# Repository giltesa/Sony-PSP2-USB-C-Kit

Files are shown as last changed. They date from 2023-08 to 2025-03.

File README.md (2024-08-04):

# Sony PSP 2 USB-C Kit

The **Sony PSP 2: USB-C Kit** is a board that allows to replace the original charging connector for a modern and standard **USB-C**.

**If your original connector is too old or damaged** and you need a new one, or **if you would like to charge your Sony PSP with a standard USB-C charger**, like the charger of your phone, laptop, you can with this board.

This board is compatible with these models:

*   Sony PSP 2000
*   Sony PSP 3000

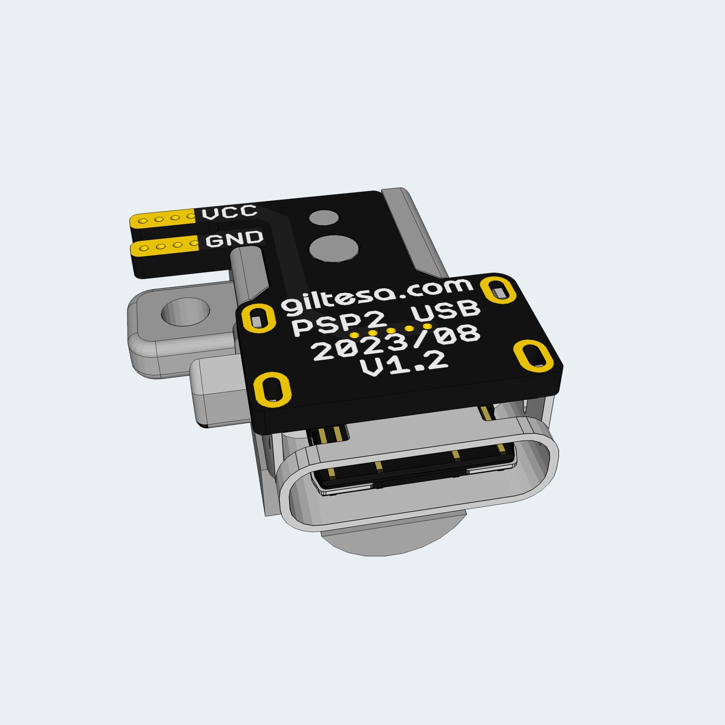
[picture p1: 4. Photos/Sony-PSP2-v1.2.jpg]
Sony-PSP-USB-C


## Would you like it?

https://shop.giltesa.com/product/sony-psp-2000-3000-usb-c-kit/

## More

- [giltesa.com](https://giltesa.com "giltesa.com")
- [twitter.com](https://twitter.com/giltesa "twitter.com")

## License

This project is licensed under a **Creative Commons** license:
**[Attribution-NonCommercial-ShareAlike 4.0 International (CC BY-NC-SA 4.0) ](https://creativecommons.org/licenses/by-nc-sa/4.0/)**

Check the [LICENSE.md](LICENSE.md) for more information.

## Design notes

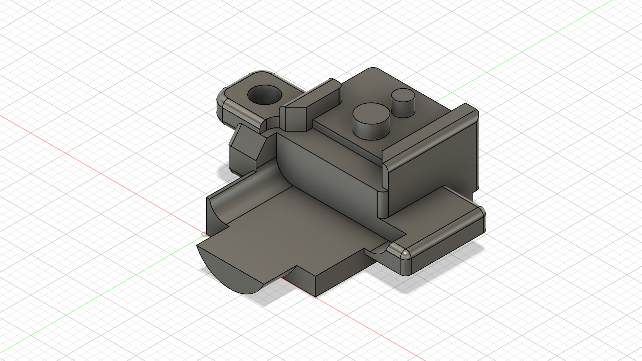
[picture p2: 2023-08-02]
2. Renders, 3D models/Plastic holder/Sony PSP 2000 v5 v14_1.png

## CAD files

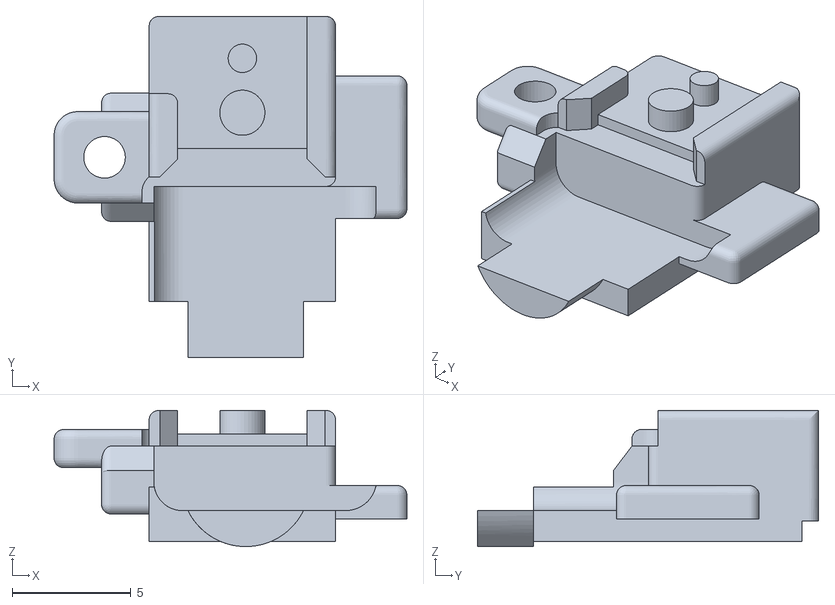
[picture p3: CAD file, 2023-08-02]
2. Renders, 3D models/Plastic holder/Sony PSP 2000 v5 v14.stl
14.9 x 14.3 x 5.73

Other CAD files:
2. Renders, 3D models/Plastic holder/Sony PSP 2000 v5 v14.f3d
2. Renders, 3D models/Sony PSP v1.2.skp

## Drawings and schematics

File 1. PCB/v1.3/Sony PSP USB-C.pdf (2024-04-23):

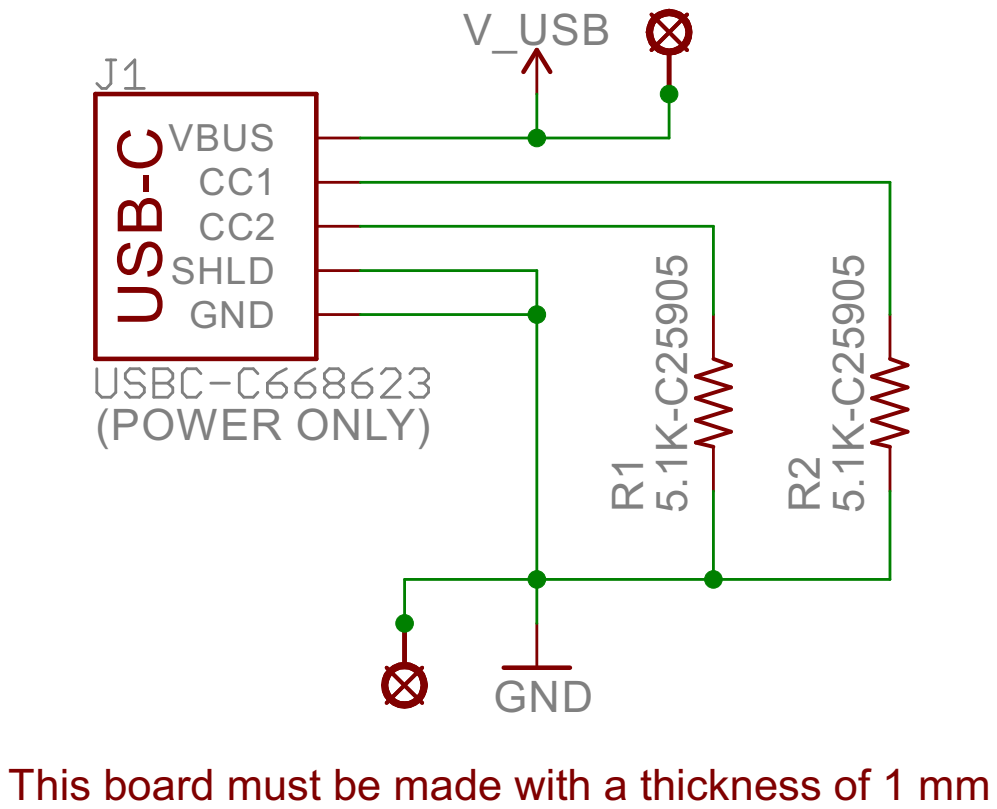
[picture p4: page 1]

This board must be made with a thickness of 1 mm

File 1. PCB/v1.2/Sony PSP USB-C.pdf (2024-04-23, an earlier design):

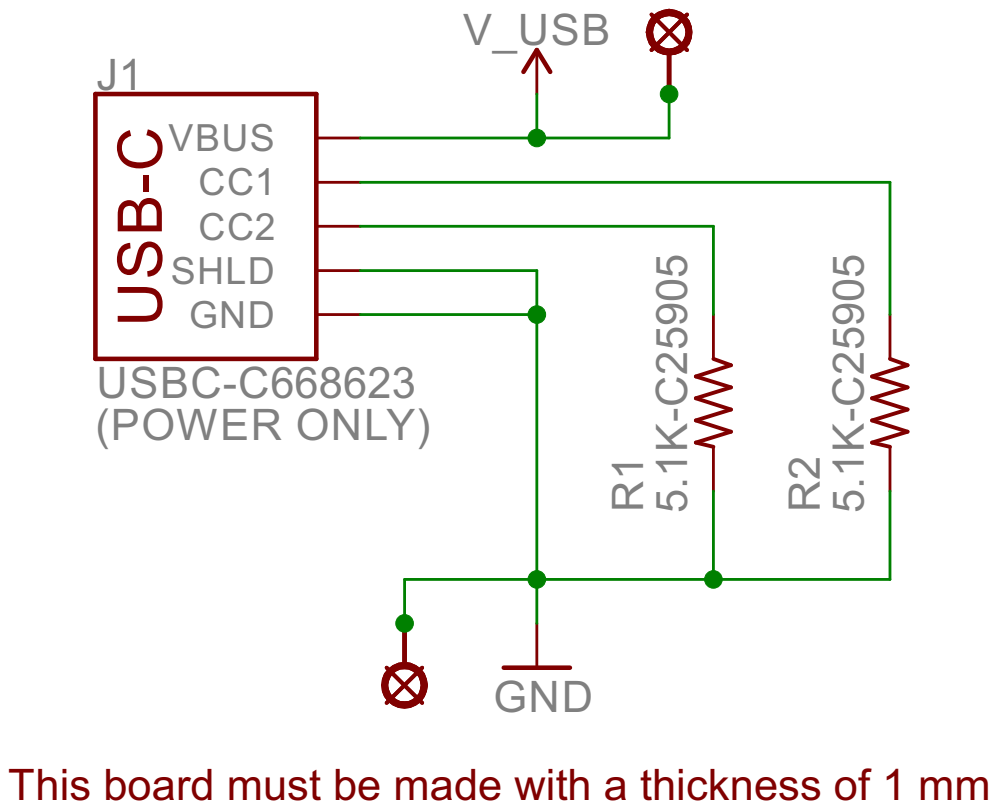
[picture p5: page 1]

This board must be made with a thickness of 1 mm

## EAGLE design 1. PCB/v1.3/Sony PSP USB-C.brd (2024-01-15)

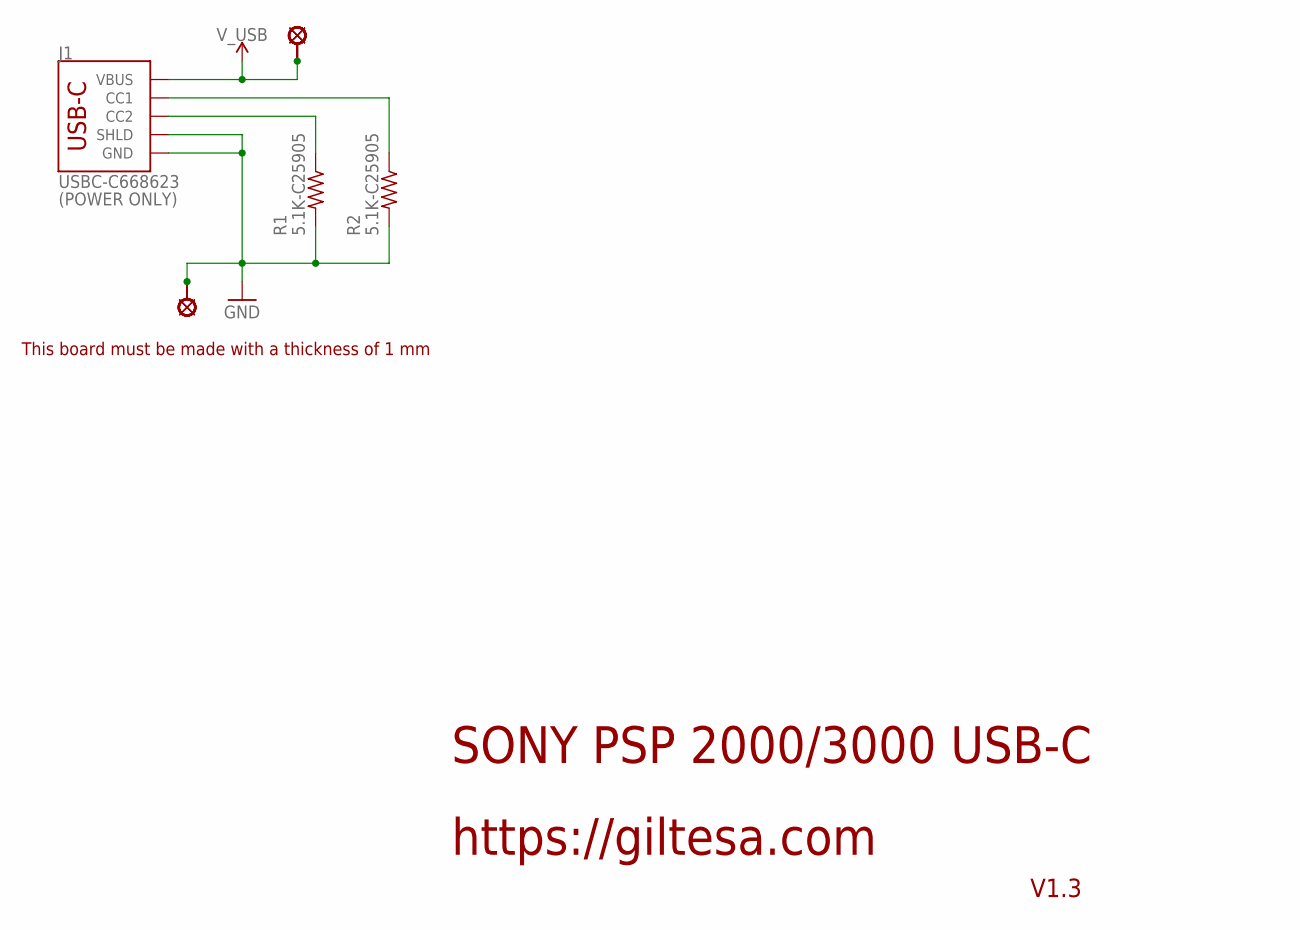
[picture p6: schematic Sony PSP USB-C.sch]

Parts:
J1: USBC-C668623; USB-C_6P
R1, R2: 5.1K-C25905; R0402
U$1, U$2, U$3, U$4: SOLDER_PAD_N3DS; N3DS_TPAD

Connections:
GND: J1.A12-GND (GND), J1.B12-GND (GND), J1.SHLD1 (SHLD), J1.SHLD2 (SHLD), J1.SHLD3 (SHLD), J1.SHLD4 (SHLD), R1.2, R2.2, U$1.1, U$4.1
unnamed: J1.B5 (CC2), R1.1
unnamed: J1.A5 (CC1), R2.1
V_USB: J1.A9-VBUS (VBUS), J1.B9-VBUS (VBUS), U$2.1, U$3.1

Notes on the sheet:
SONY PSP 2000/3000 USB-C
https://giltesa.com
V1.3
This board must be made with a thickness of 1 mm
(POWER ONLY)

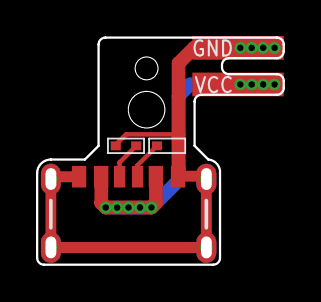
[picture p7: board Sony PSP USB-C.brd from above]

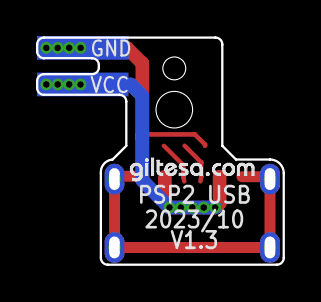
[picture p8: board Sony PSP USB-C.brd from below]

Board: 2 copper layers, 13.7 x 12.6 mm, 8 parts (3 on the bottom side), 4 nets.

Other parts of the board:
U$11: GILTESA.COM_MASK_7MM

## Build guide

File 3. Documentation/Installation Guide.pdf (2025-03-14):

# USB-C KIT For

# Sony PSP 2000 Sony PSP 3000

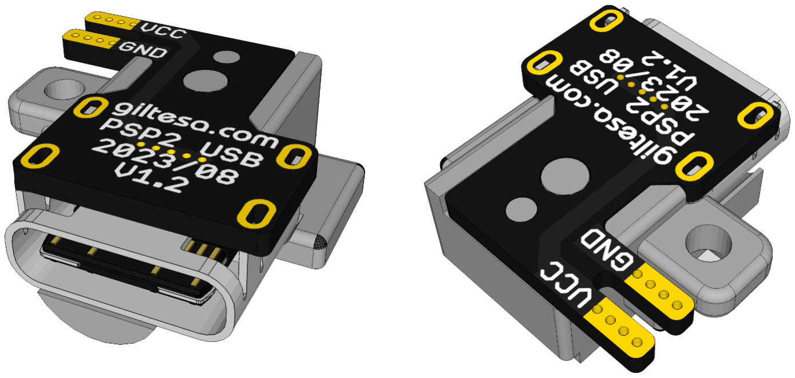
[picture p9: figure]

### PRODUCT

HTTPS://SHOP.GILTESA.COM/PRODUCT/SONY-PSP-2000-3000-USB-C-KIT

# PLEASE READ THROUGH THESE INSTRUCTIONS

ENTIRELY BEFORE ATTEMPTING TO INSTALL.

# WARNING: IF YOU ARE NOT COMFORTABLE WITH SOLDERING, OR PERFORMING ANY STEP IN THIS

GUIDE, DO NOT PERFORM THE INSTALL YOURSELF.

# FIND SOMEONE WHO IS COMFORTABLE TO DO IT FOR

YOU.

INDEX

# Description

The Sony PSP: USB-C Kit is a board that allows to replace the original charging connector for a modern and standard USB-C.

If your original connector is too old or damaged and you need a new one, or if you would like to charge your Sony PSP with a standard USB-C charger, like the charger of your phone, laptop, you can with this kit.

This board is compatible with these two models:

- Sony PSP 2000
- Sony PSP 3000

# FEATURES

- Plastic holder made by resin 3D printer.
- Charging your Sony PSP with:
- USB power banks
- USB-A chargers
- USB-C chargers
- USB-C PD chargers (normal speed, not fast)
- USB-A to USB-C cables
- USB-C to USB-C cables

# INCLUDED

- 1 board.
- 1 plastic part to holder the USB board (random color: Grey/Black)
- 2 Heat shrink tube.

# Recommended / REQUIRED (NOT INCLUDED)

- The power cable from the original connector.
- Phillips screwdriver
- Soldering iron
- Tin
- Cutting plier
- Cutter
- Tweezers
- Instant glue (Loctite, Super Glue)

# Board details

This tiny board has 2 pads in about 2cm²
surface, which means it requires good soldering skills. The following explains what each pad is for.
Version 1.2 and earlier: | Version 1.3 and onwards:

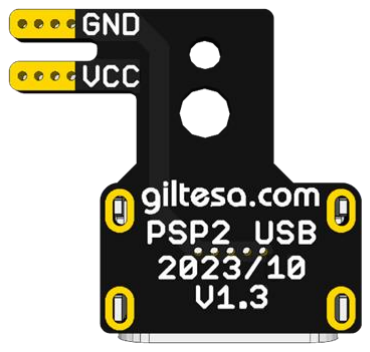
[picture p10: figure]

The pads are inverted, as we noticed that this prevents the cables from twisting during installation.

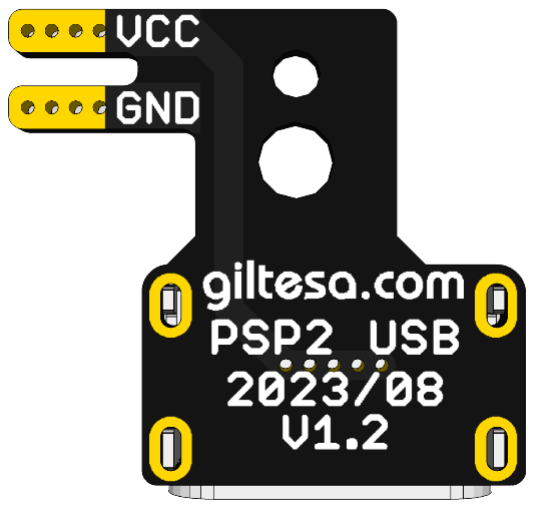
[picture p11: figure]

The pads are:

1. VCC: | The 5V line from the USB-C.
2. GND: | The ground pad.

# Test the board!

Before starting the installation, you should test the board. If it doesn’t work contact me for a replacement (https://shop.giltesa.com/refund-policy/) (all boards are fully tested, but they may damage during the shipping, we try to package them as better as possible), if it works, go ahead with the installation.

Connect the power from your USB charger to the USB-C connector on the board. Then, with a multimeter in voltage measurement mode, check for a 5V reading. If that's the case, continue with the installation.

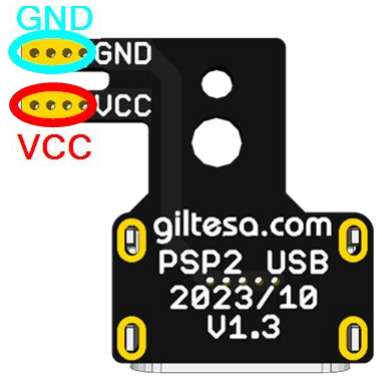
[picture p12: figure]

# INSTALLATION STEPS

## Pre installation Steps

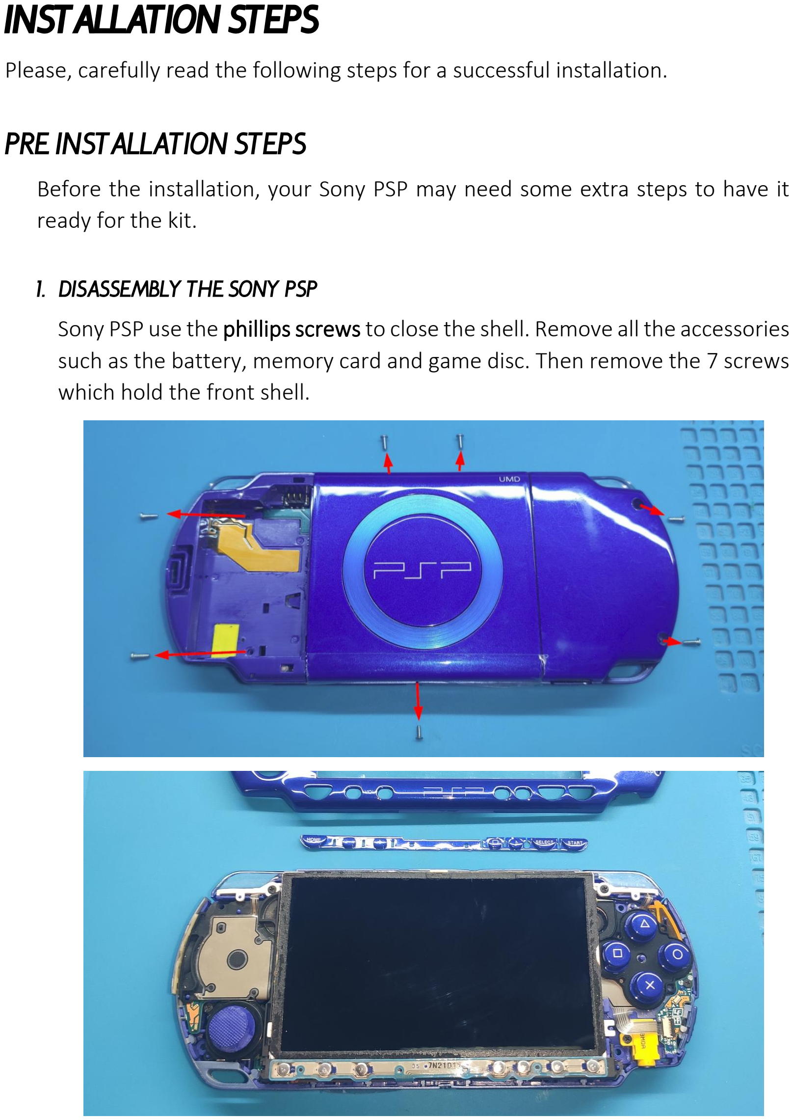
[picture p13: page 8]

Please, carefully read the following steps for a successful installation.

Before the installation, your Sony PSP may need some extra steps to have it ready for the kit.

1. Disassembly the Sony PSP

Sony PSP use the phillips screwsto close the shell. Remove all the accessories such as the battery, memory card and game disc. Then remove the 7 screws which hold the front shell.

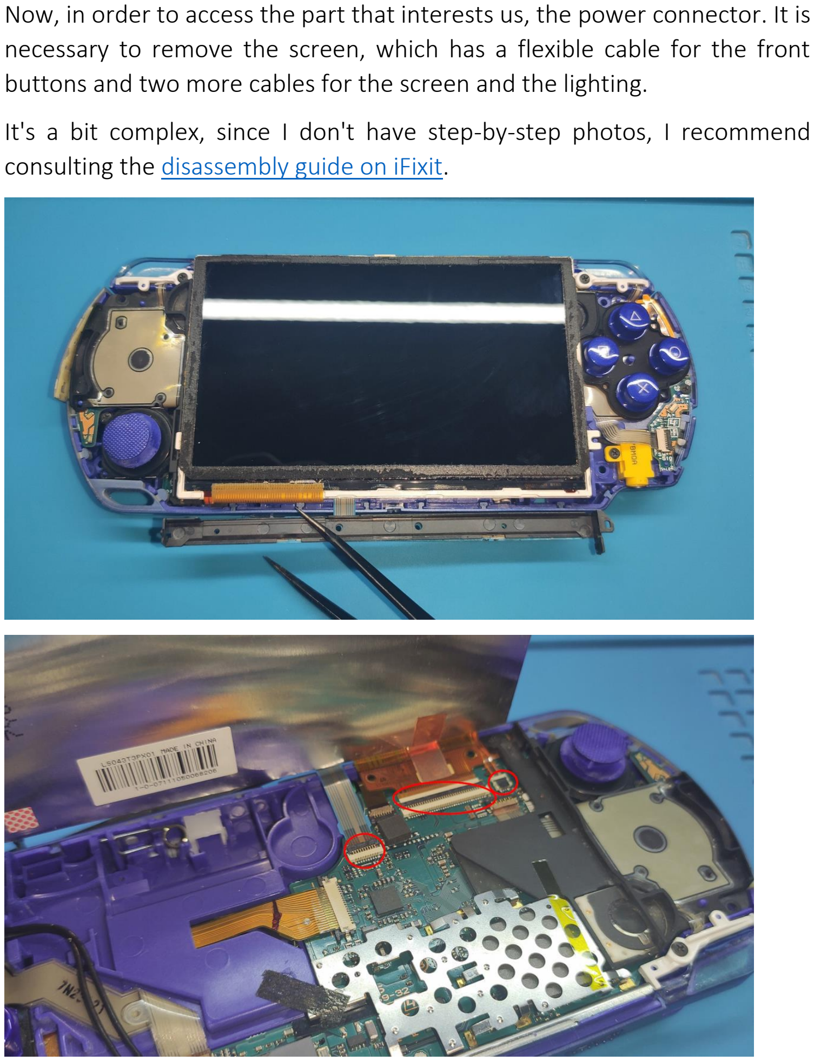
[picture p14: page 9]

Now, in order to access the part that interests us, the power connector. It is necessary to remove the screen, which has a flexible cable for the front buttons and two more cables for the screen and the lighting.

It's a bit complex, since I don't have step-by-step photos, I recommend consulting the disassembly guide on iFixit. (https://www.ifixit.com/Guide/PSP+2000+Logic+Board+Replacement/1272)

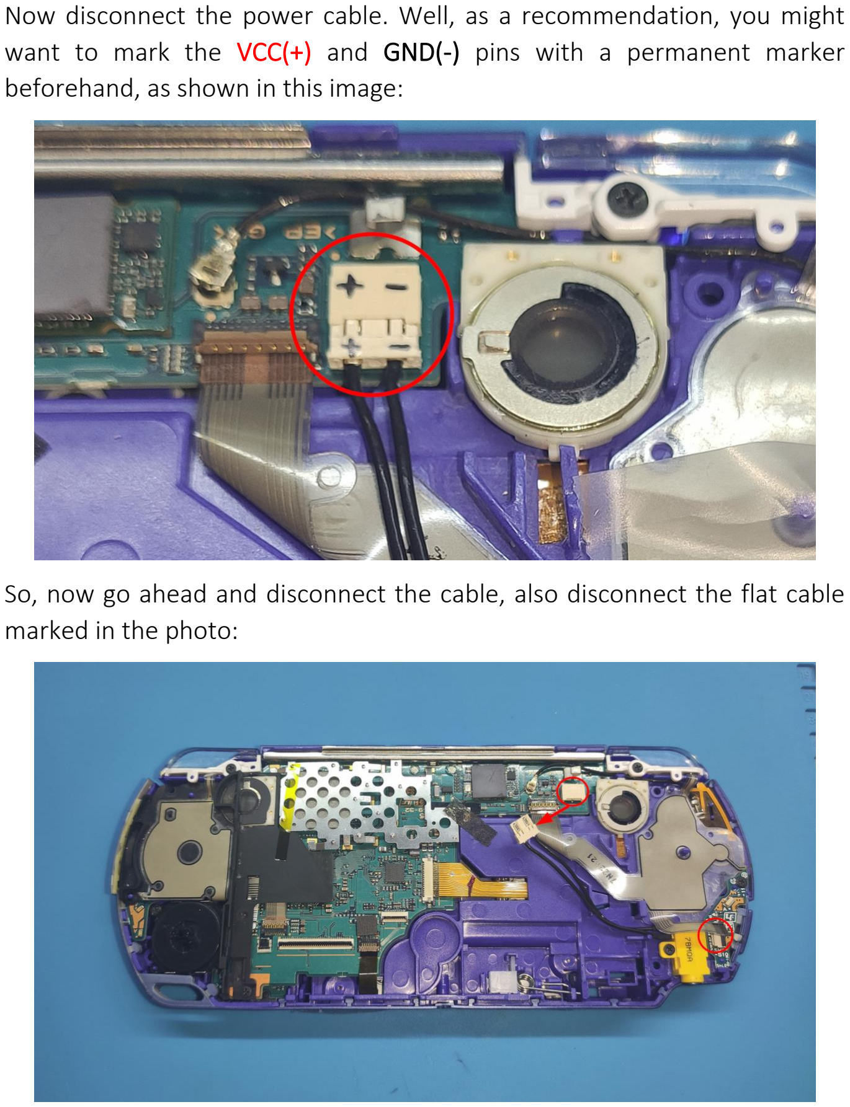
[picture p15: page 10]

Now disconnect the power cable. Well, as a recommendation, you might want to mark the VCC(+) and GND(-) pins with a permanent marker beforehand, as shown in this image:

So, now go ahead and disconnect the cable, also disconnect the flat cable marked in the photo:

## installation Steps

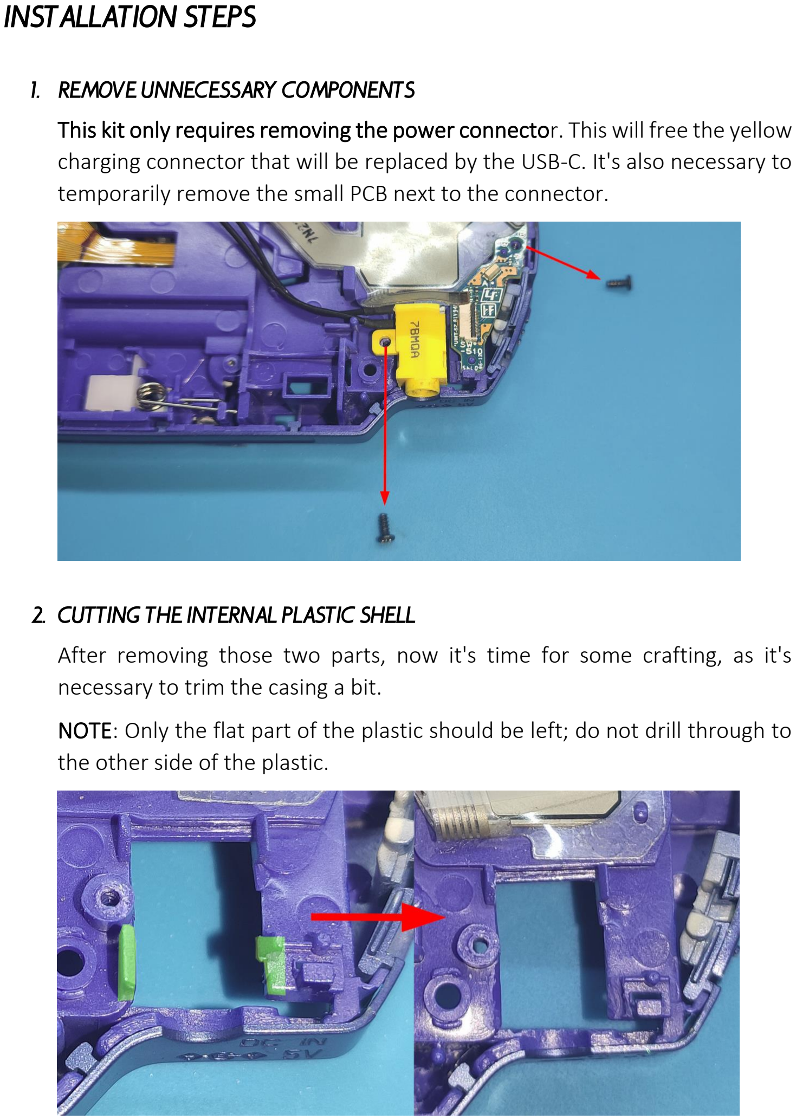
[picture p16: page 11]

1. Remove unnecessary components

This kit only requires removing the power connector. This will free the yellow charging connector that will be replaced by the USB-C. It's also necessary to temporarily remove the small PCB next to the connector.

2. Cutting the internal plastic shell

After removing those two parts, now it's time for some crafting, as it's necessary to trim the casing a bit.

NOTE: Only the flat part of the plastic should be left; do not drill through to the other side of the plastic.

Once the plastic has been sufficiently trimmed, you can place the plastic support provided with the kit. It should be completely flat and snug. Depending on your PSP's shell, you may need to trim it further. Take your time and check at each step if you have trimmed the plastic enough to fit the kit piece.

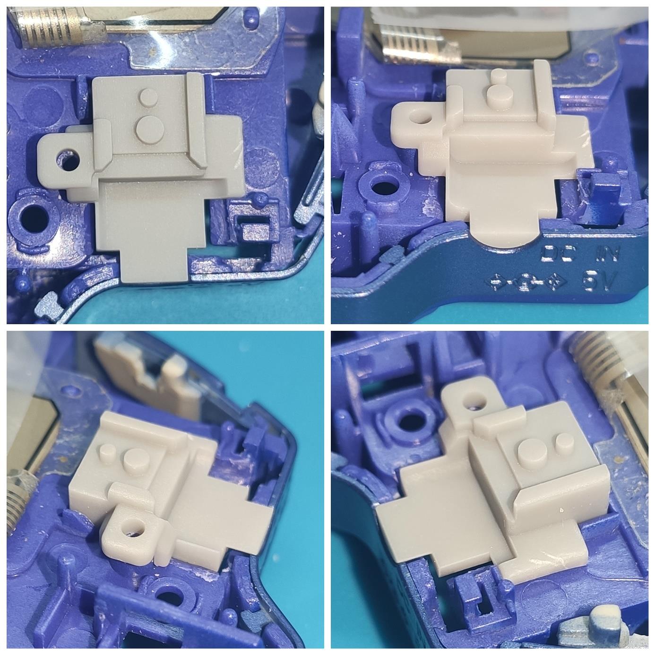
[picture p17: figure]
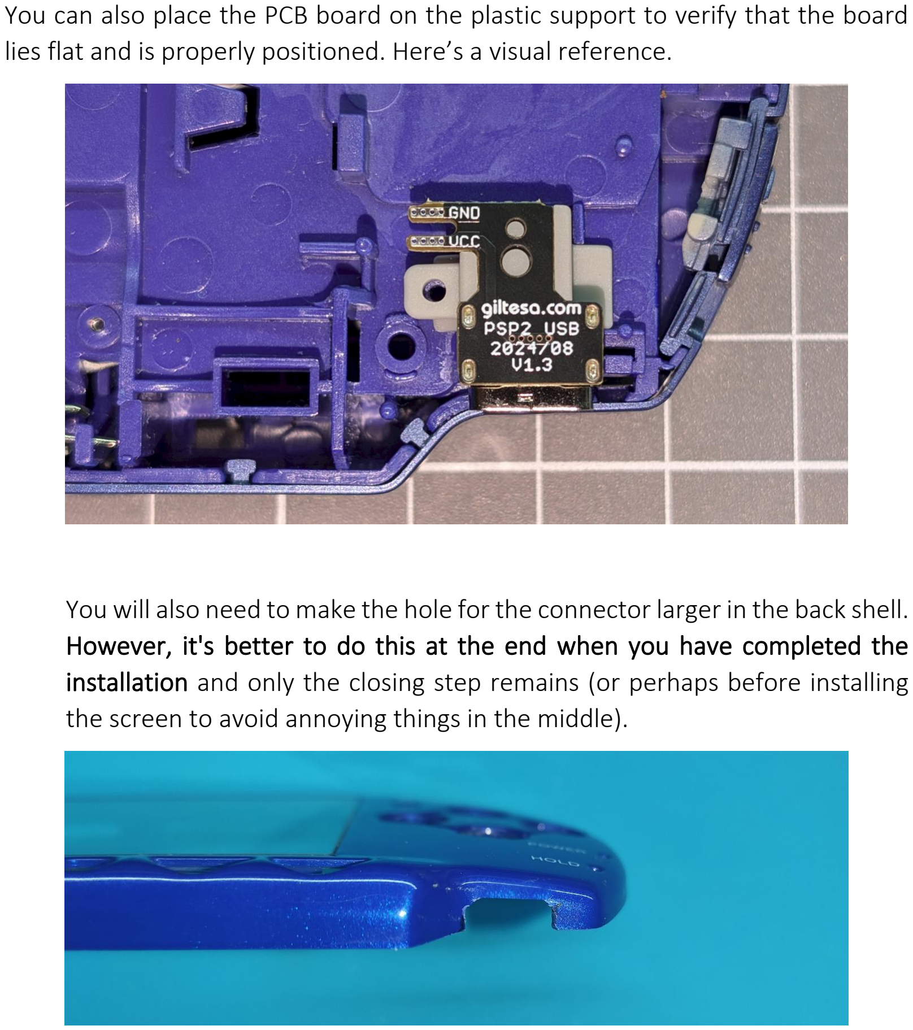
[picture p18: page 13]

You can also place the PCB board on the plastic support to verify that the board lies flat and is properly positioned. Here’s a visual reference.

You will also need to make the hole for the connector larger in the back shell. However, it's better to do this at the end when you have completed the installation and only the closing step remains (or perhaps before installing the screen to avoid annoying things in the middle).

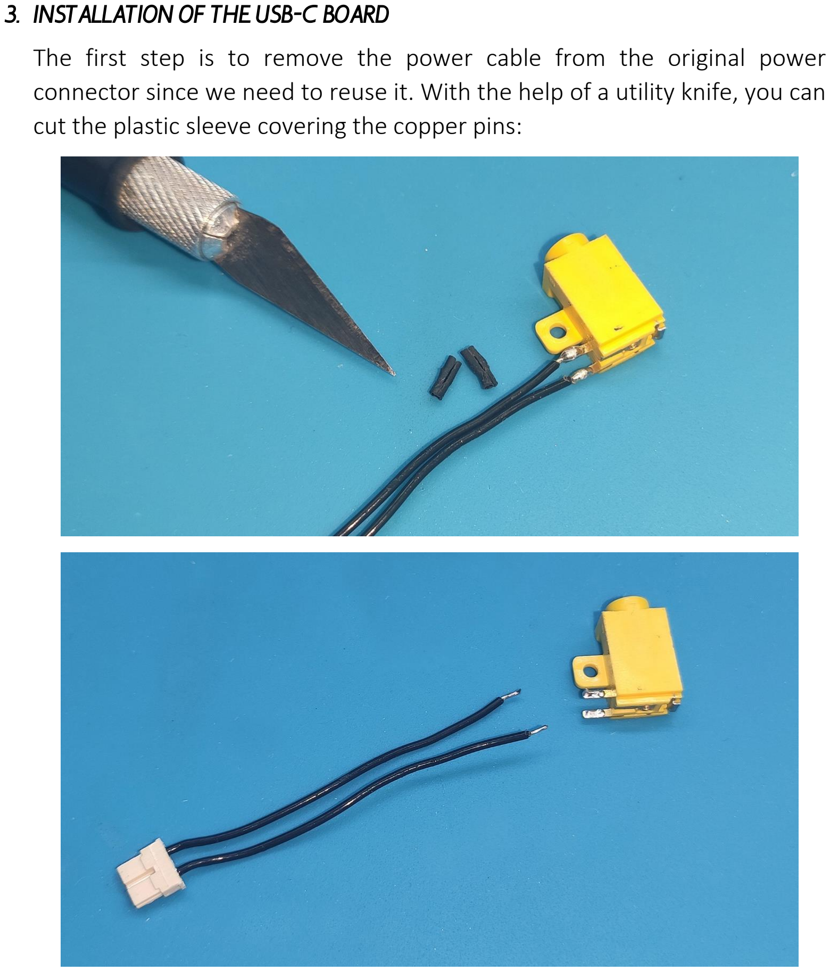
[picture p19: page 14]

3. Installation of the USB-C board

The first step is to remove the power cable from the original power connector since we need to reuse it. With the help of a utility knife, you can cut the plastic sleeve covering the copper pins:

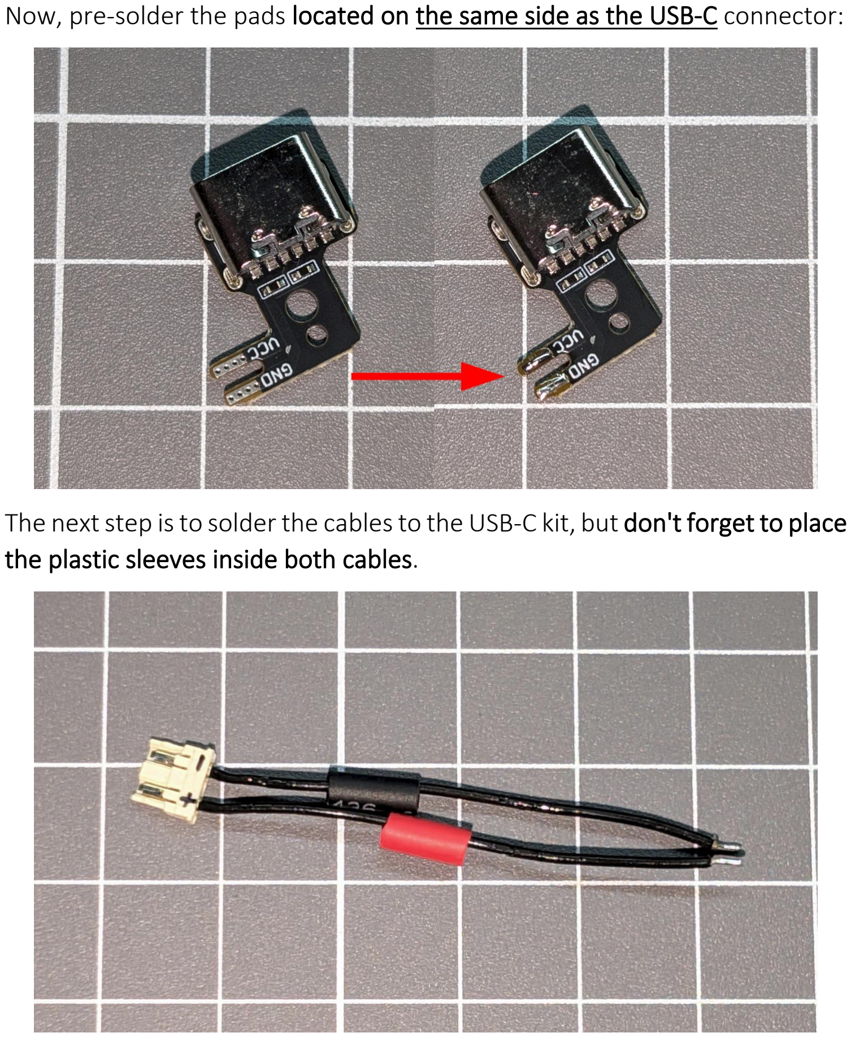
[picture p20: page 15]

Now, pre-solder the pads located on the same side as the USB-C connector:

The next step is to solder the cables to the USB-C kit, but don't forget to place the plastic sleeves inside both cables.

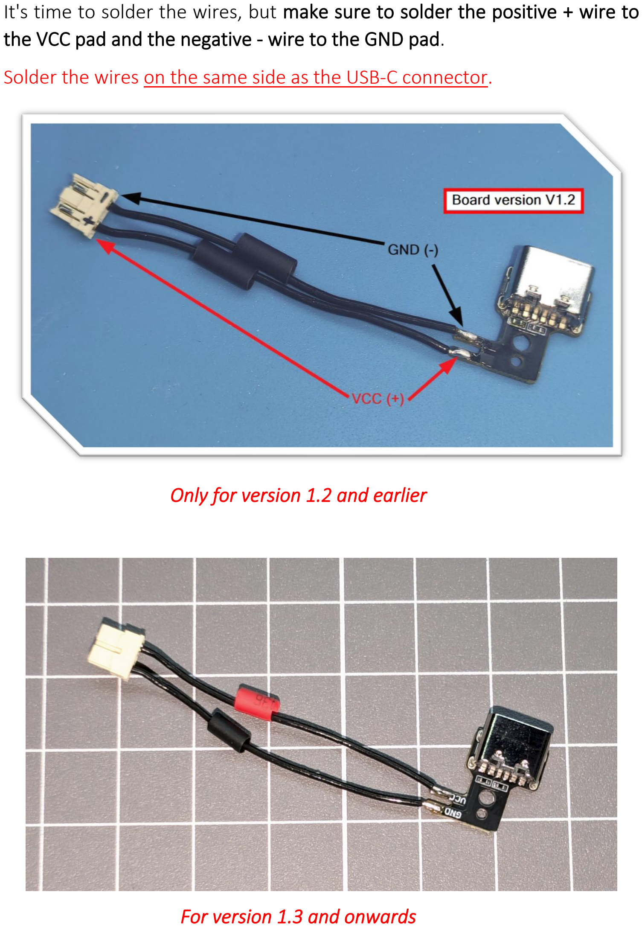
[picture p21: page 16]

It's time to solder the wires, but make sure to solder the positive + wire to the VCC pad and the negative - wire to the GND pad.

Solder the wires on the same side as the USB-C connector.

Only for version 1.2 and earlier

For version 1.3 and onwards

Place the plastic sleeves in position and apply heat, for example, using a lighter, but be careful not to burn the unprotected part of the cables. If you have kapton tape, you can use it to protect the cable.

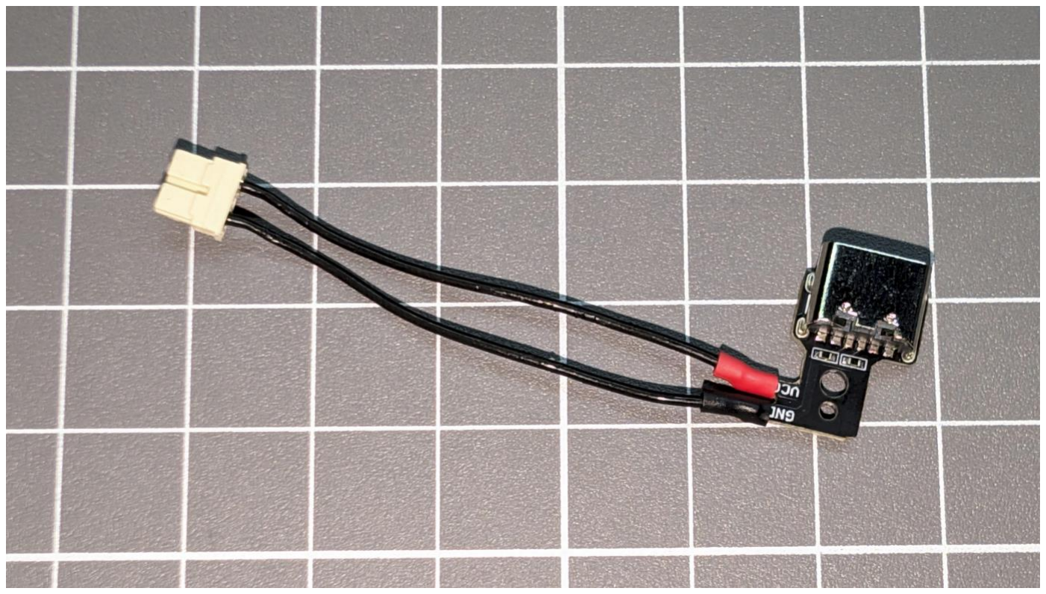
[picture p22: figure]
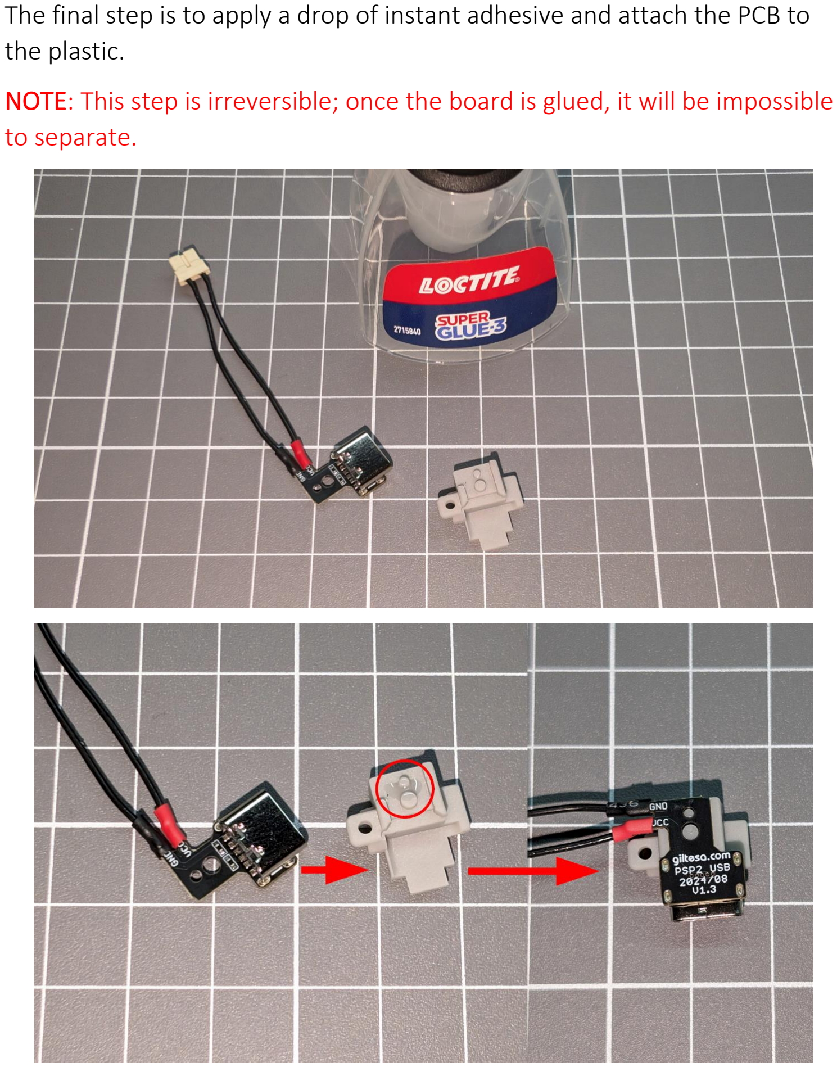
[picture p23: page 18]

The final step is to apply a drop of instant adhesive and attach the PCB to the plastic.

NOTE: This step is irreversible; once the board is glued, it will be impossible to separate.

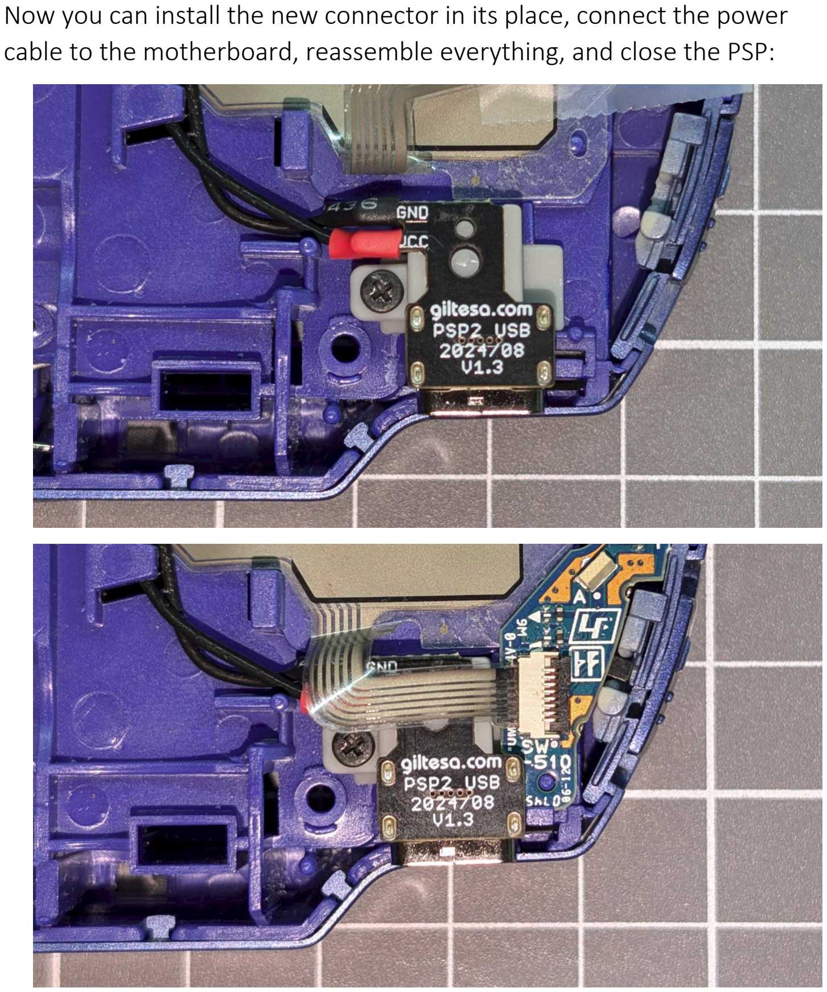
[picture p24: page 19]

Now you can install the new connector in its place, connect the power cable to the motherboard, reassemble everything, and close the PSP:

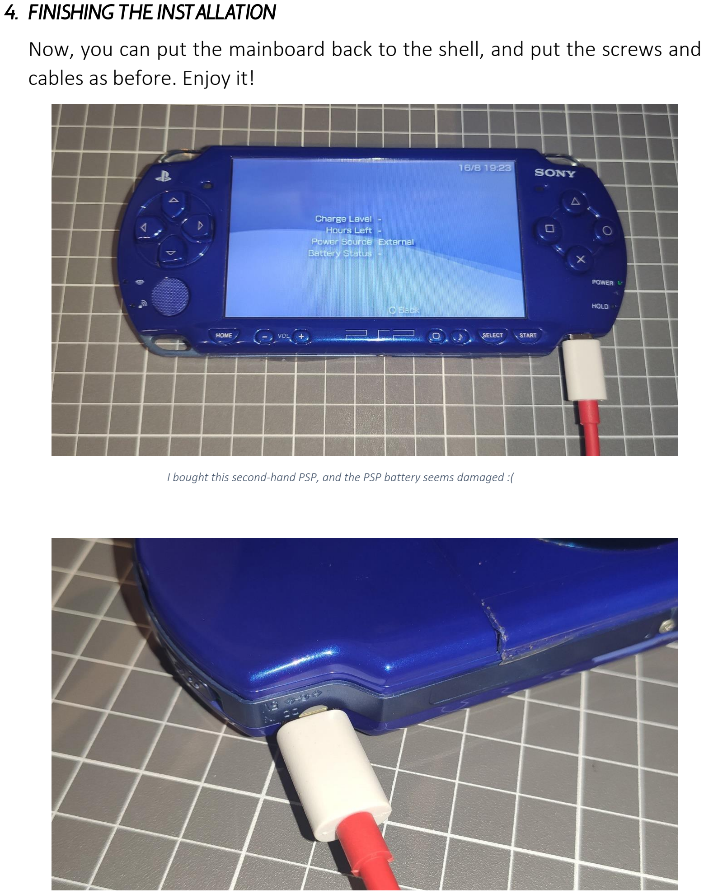
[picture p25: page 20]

4. Finishing the installation

Now, you can put the mainboard back to the shell, and put the screws and cables as before. Enjoy it!

I bought this second-hand PSP, and the PSP battery seems damaged :(

# Frequently Asked Questions - FAQ

What charger can be used?
You can use any standard charger for mobile phones, computers, etc., with 5V 1A. It doesn't need to be a Power Delivery charger since this feature is not used. Of course, if you want to use a Power Delivery charger, there's no problem or risk.

Technical data for curious minds:

Power Delivery chargers can supply a wide range of voltages: 5V, 9V, 12V, 15V, and 20V. However, for this to happen, the device must communicate with the charger to explicitly request the desired voltage. Without this communication, the charger will never supply more than 5V. That's one of the advantages of USB-C, as it can be used with both old and modern devices.

The console doesn't charge with USB-C to USB-C cables/chargers.
All our kits incorporate two resistors to indicate to the charger that it is a legacy device and should charge at a maximum of 5V.

The only reason one might consider for it not working is that one might be using a charger/cable from Apple or another company that doesn't follow the standard 100%. Trying other cables, for example from the Nintendo Switch, a laptop, or another mobile device, should work.

The console is still not charging.
Although all our products are tested before being packaged, please verify that the product is working correctly.

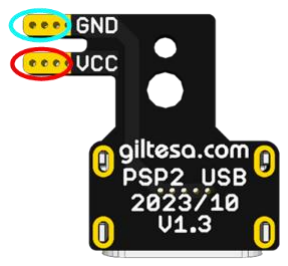
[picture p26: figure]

To do this, use a multimeter in voltage measurement
mode. Connect the USB-C cable to the board and
check that there is a 5V reading on these two pads.

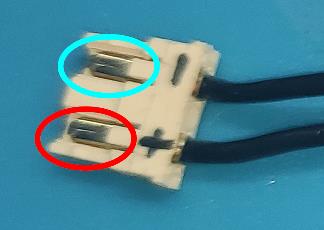
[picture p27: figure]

If you get the measurement, then the issue is not with the board but with the installation or/and the console. Solder the wires and perform the same test from the power connector. You should get a 5V reading. If you get -5V, then you have soldered the wires in the wrong orientation.

If you continue to get a 5V reading, then the issue is not with the cable or its soldering to the board.

Connect the cable to the mainboard connector and
repeat the same test.

If everything is fine up to this point, then check the console's fuses; (https://www.google.com/search?q=psp+2000+mainboard+fuses&udm=2) there might be a blown one.

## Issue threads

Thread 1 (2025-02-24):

Which side to solder the cables

schorr31, 2025-02-24:
Could you add a hint in the installation guide which side to solder the cable to the USB-C board?

I know you can see it in the pictures but at first i soldered the cable to the topside but the display does not fit anymore because the cable are in the way of the holder.

giltesa, 2025-02-25:
Hello schorr31,

The manual is now updated with new images and clarifying texts.
Thanks again for your feedback.

Kind regards,
giltesa

Closed 2025-02-25.

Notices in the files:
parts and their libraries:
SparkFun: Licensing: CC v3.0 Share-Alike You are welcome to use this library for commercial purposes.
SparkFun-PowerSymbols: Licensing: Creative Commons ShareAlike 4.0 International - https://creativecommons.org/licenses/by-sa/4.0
